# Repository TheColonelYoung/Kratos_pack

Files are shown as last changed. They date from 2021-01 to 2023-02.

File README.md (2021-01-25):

# Kratos pack
Battery case with electronics for charging and protection of battery cells. Composes of 2s li-ion 3,7V battery cells. Includes undervoltage, overvoltage and overcurrent protection. As well as reverse voltage protection. Is charged from USB type-C connector. Support statistics over USB and have battery voltage indication via RGB LED.

 Front | Back |
-------------------------|-------------------------|
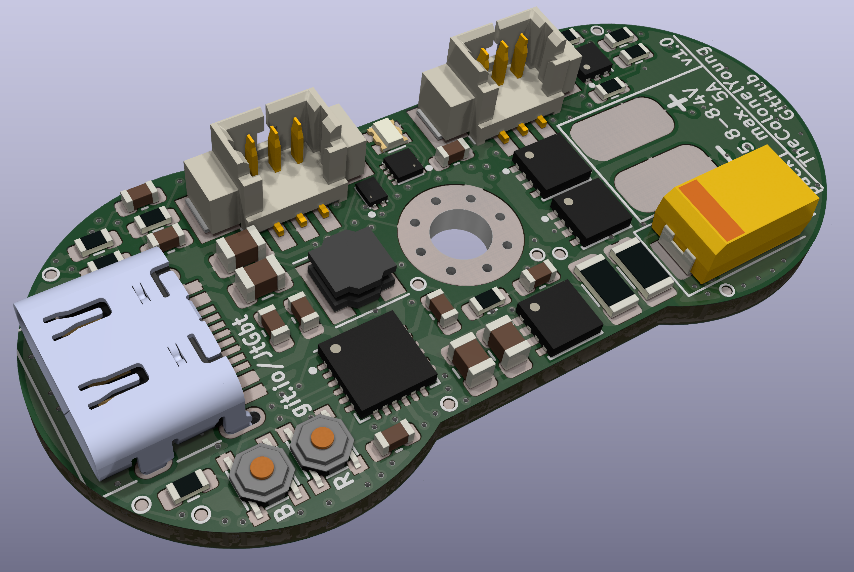
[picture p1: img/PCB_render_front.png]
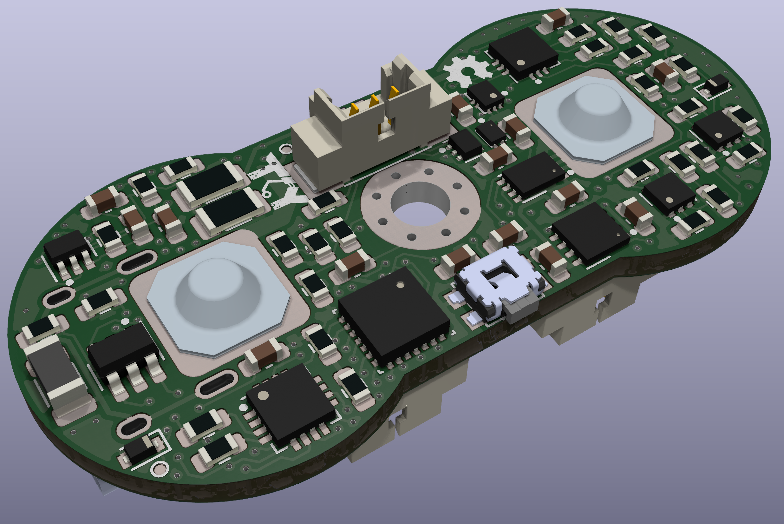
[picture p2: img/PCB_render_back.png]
 | 

PCB is placed on top of batteries, so contact on bottom of board touch positive side of one battery and negative of other.
On other side batteries are connected only with metal bridge with spring contact to which is soldered cable which leads to connector on board. This wire is used to read voltage of individual batteries and balance then during charging.

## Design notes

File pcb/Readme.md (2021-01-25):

# PCB parameter
- 4 layer PCB
- 1 oz copper
- Minimal trace width 0.127 mm
- Via drilling 0.2, via copper 0.45 mm
- Thickness 1.6 mm
- Dimensions: 44.2 x 20.2 mm

# Connectors
### USB-C
- Supports USB 2.0
- Current up to 3A
- Bottom plastic bump for alignment should be removed to fit to board

### PROG connector
- Used to program STM32 microcontroller
- Contains SWD interface

### Debug connector
- Used to debug code in microcontroller
- Contains UART2 od microcontroller
- Pins: ground, RX, TX

### Battery connector
- Connects between batteries and to termistor
- Connect in midpoint of battery pack, used to sense voltage and ballance cells

### Output leads
- Solder pads for output wire
- Preferred connector on output is male XT30
- Output wire should be fixed with some type of strain relief

# Links
- 3 pin connectors 
    - Male [Mouser](https://mouser.com/ProductDetail/649-10114826-00003/)
    - Female [Mouser](https://mouser.com/ProductDetail/649-10114828-11103LF/)
    - Terminals [Mouser](https://mouser.com/ProductDetail/649-10114827-002LF/)
- Horizontal tactile switch [Mouser](https://mouser.com/ProductDetail/667-EVQP7J01P/)
- Tactile switches [Mouser](https://mouser.com/ProductDetail/611-KMT031NGJLHS/)
- LED 0606 [Mouser](https://mouser.com/ProductDetail/710-150066M153000/)
- LED Driver [Mouser](https://mouser.com/ProductDetail/389-KTD2026BEWETR/)

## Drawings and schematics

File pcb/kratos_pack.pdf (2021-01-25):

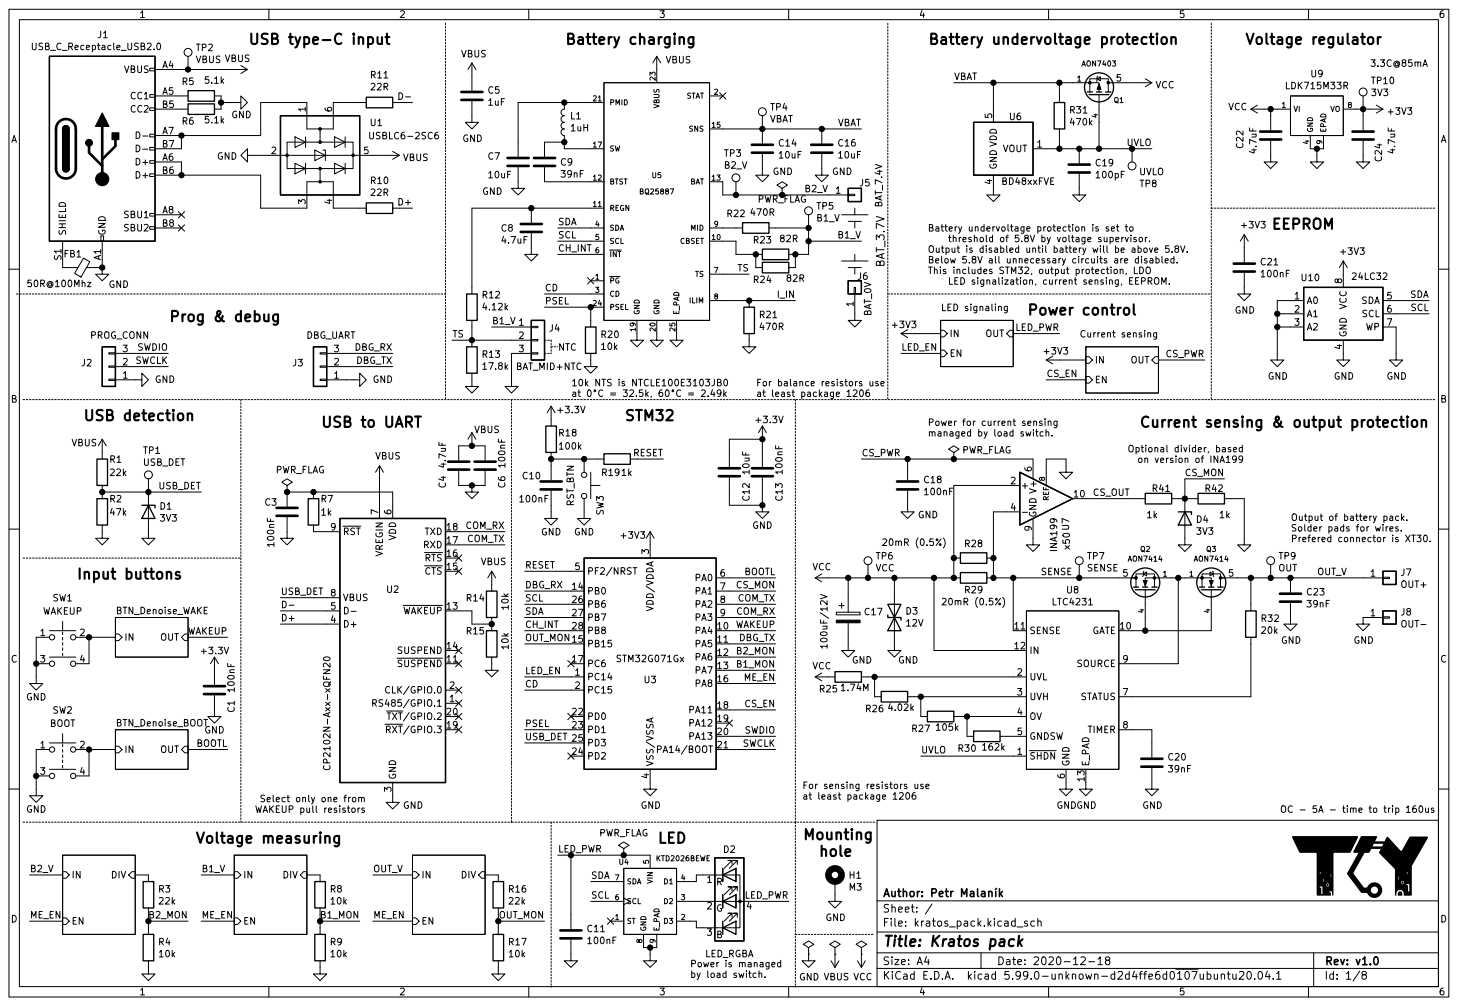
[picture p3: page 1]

on version of INA199 Voltage regulator

Solder pads for wires. Prefered connector is XT30. BAT_3.7V

Battery undervoltage protection is set to
threshold of 5.8V by voltage supervisor.
Output is disabled until battery will be above 5.8V.
Below 5.8V all unnecessary circuits are disabled.
This includes STM32, output protection, LDO

Power control For balance resistors use

4 SDA 5 SCL 6 WP 7 VCC

Power for current sensing

Output of battery pack.

6 STATUS 7 TIMER 8 SOURCE 9 GATE 10 SENSE 11

For sensing resistors use
at least package 1206

Select only one from
WAKEUP pull resistors

OC - 5A - time to trip 160us

Id: 1/8 Title: Kratos pack

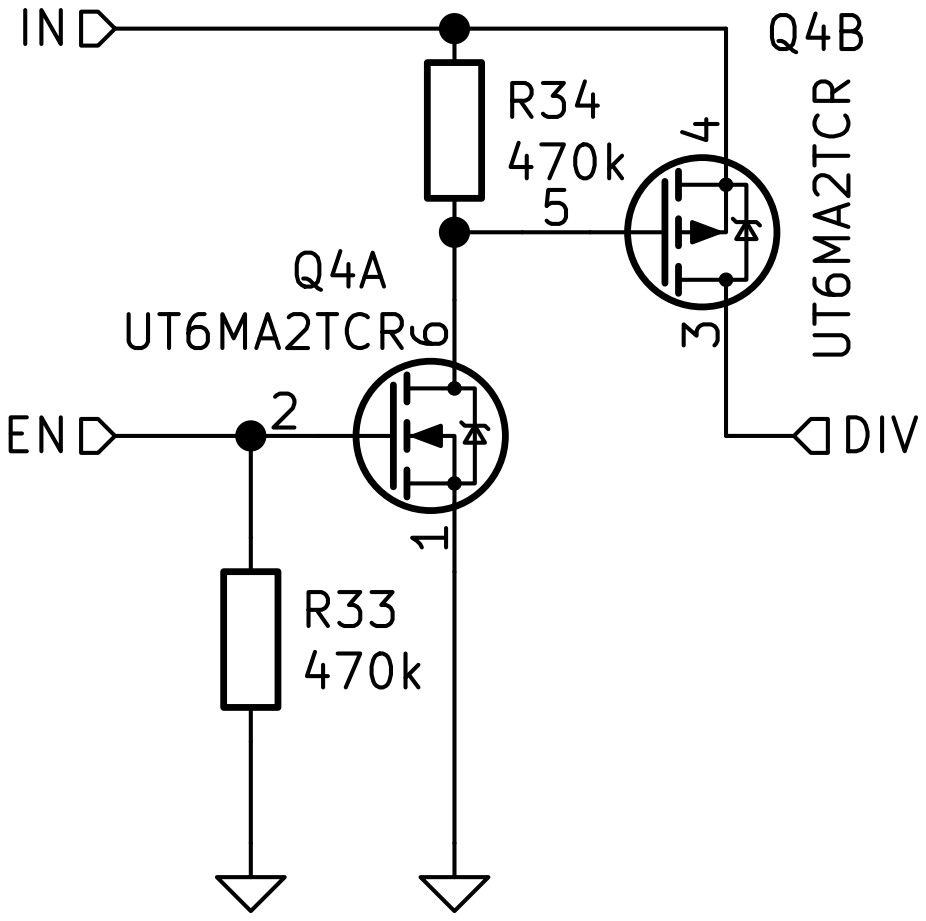
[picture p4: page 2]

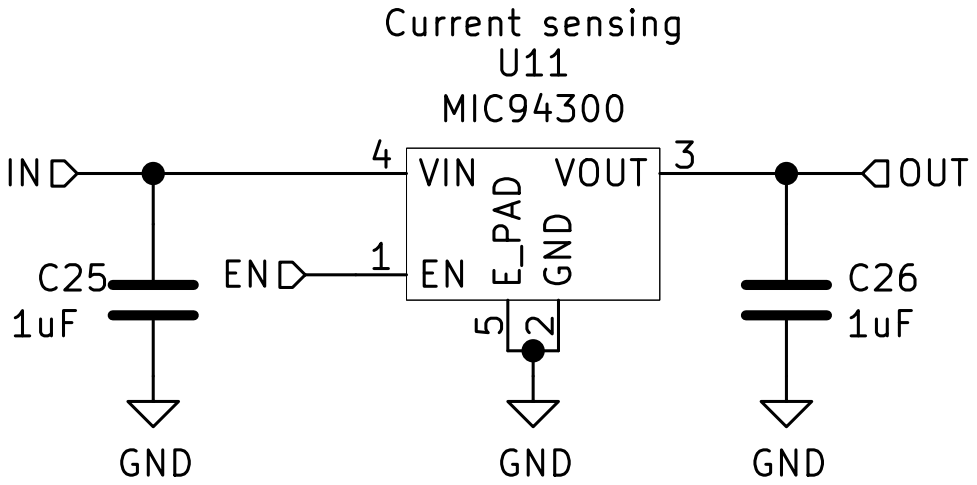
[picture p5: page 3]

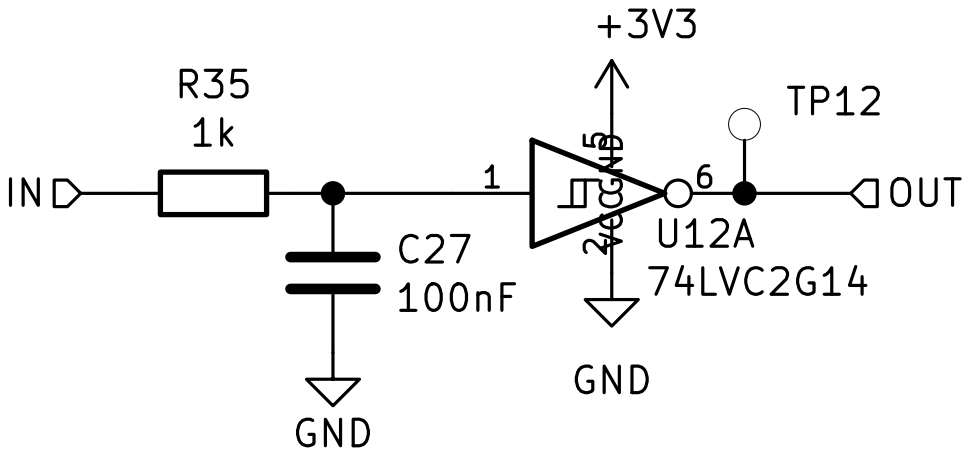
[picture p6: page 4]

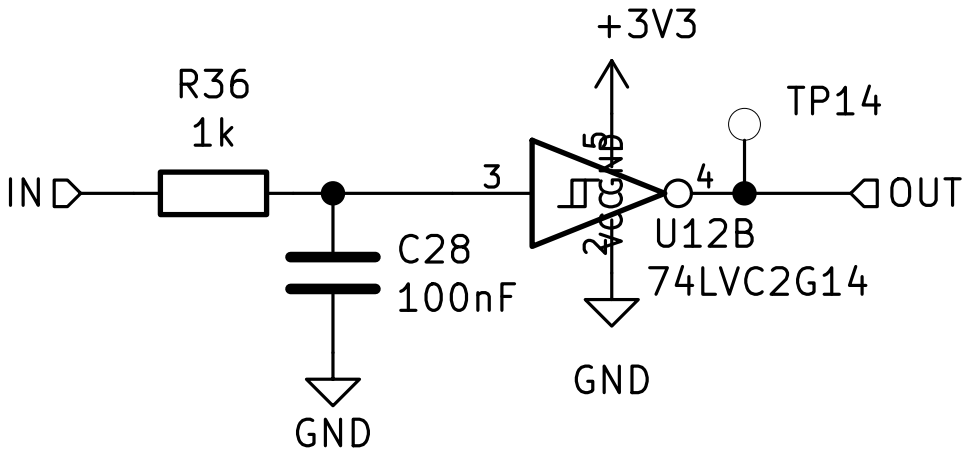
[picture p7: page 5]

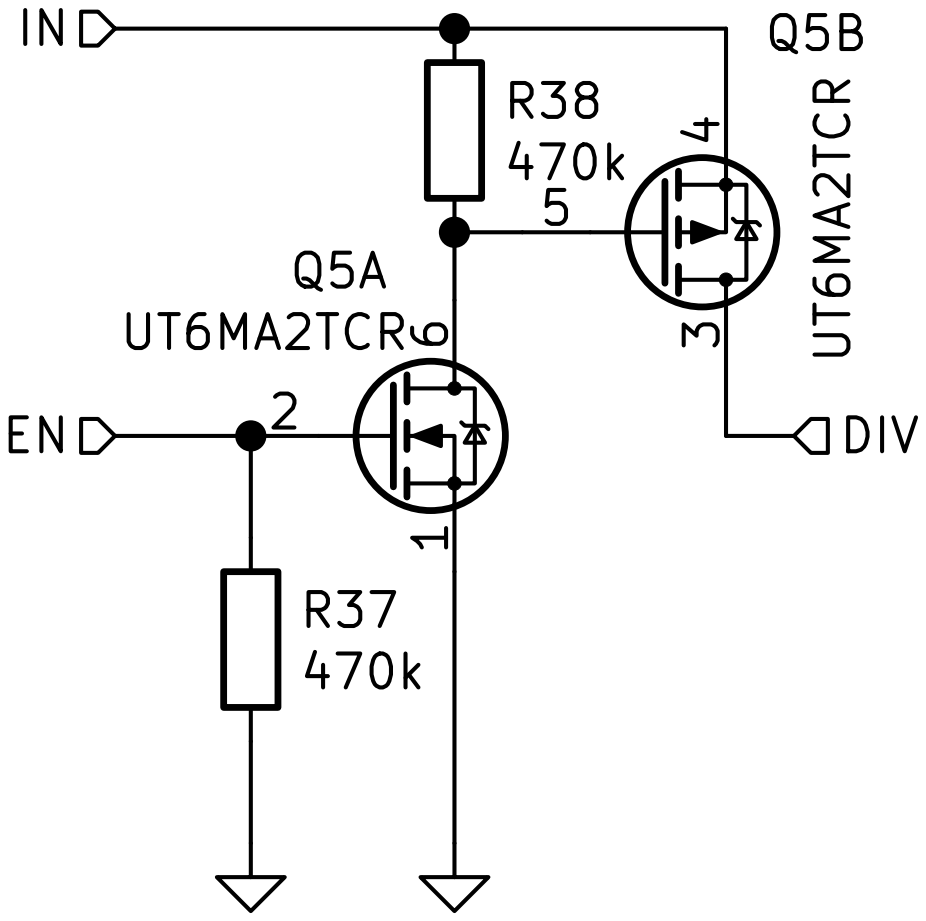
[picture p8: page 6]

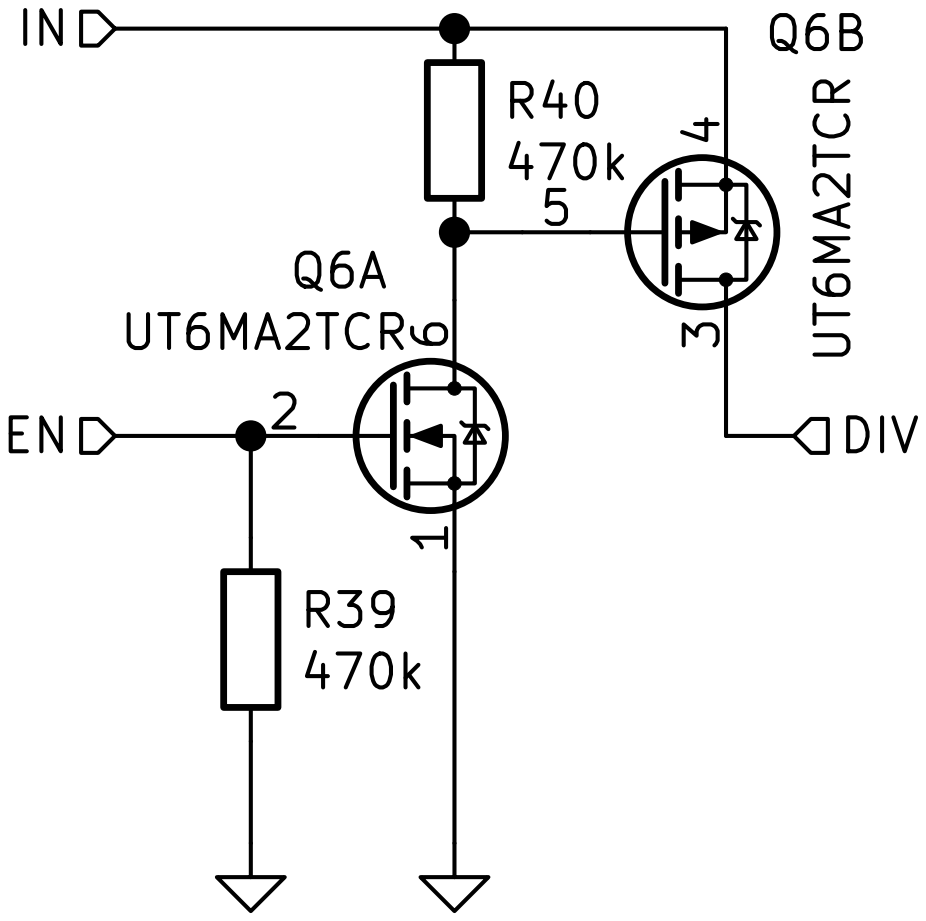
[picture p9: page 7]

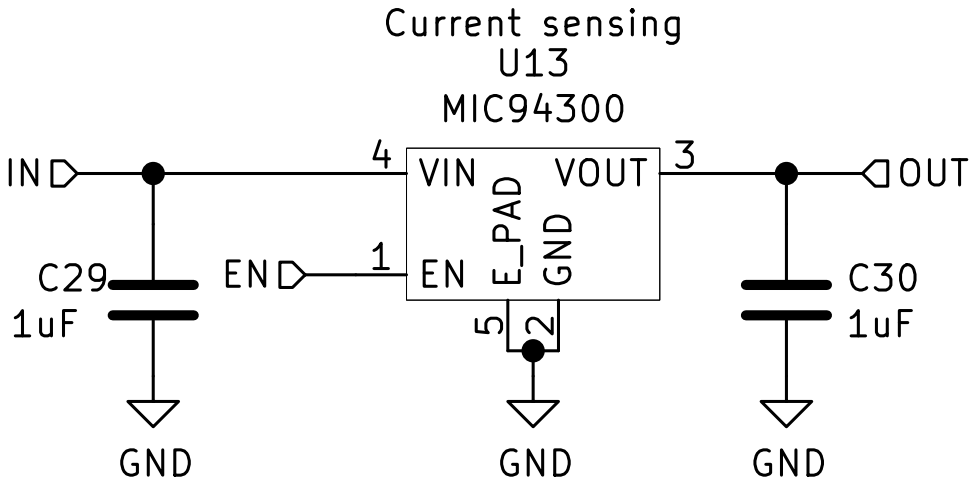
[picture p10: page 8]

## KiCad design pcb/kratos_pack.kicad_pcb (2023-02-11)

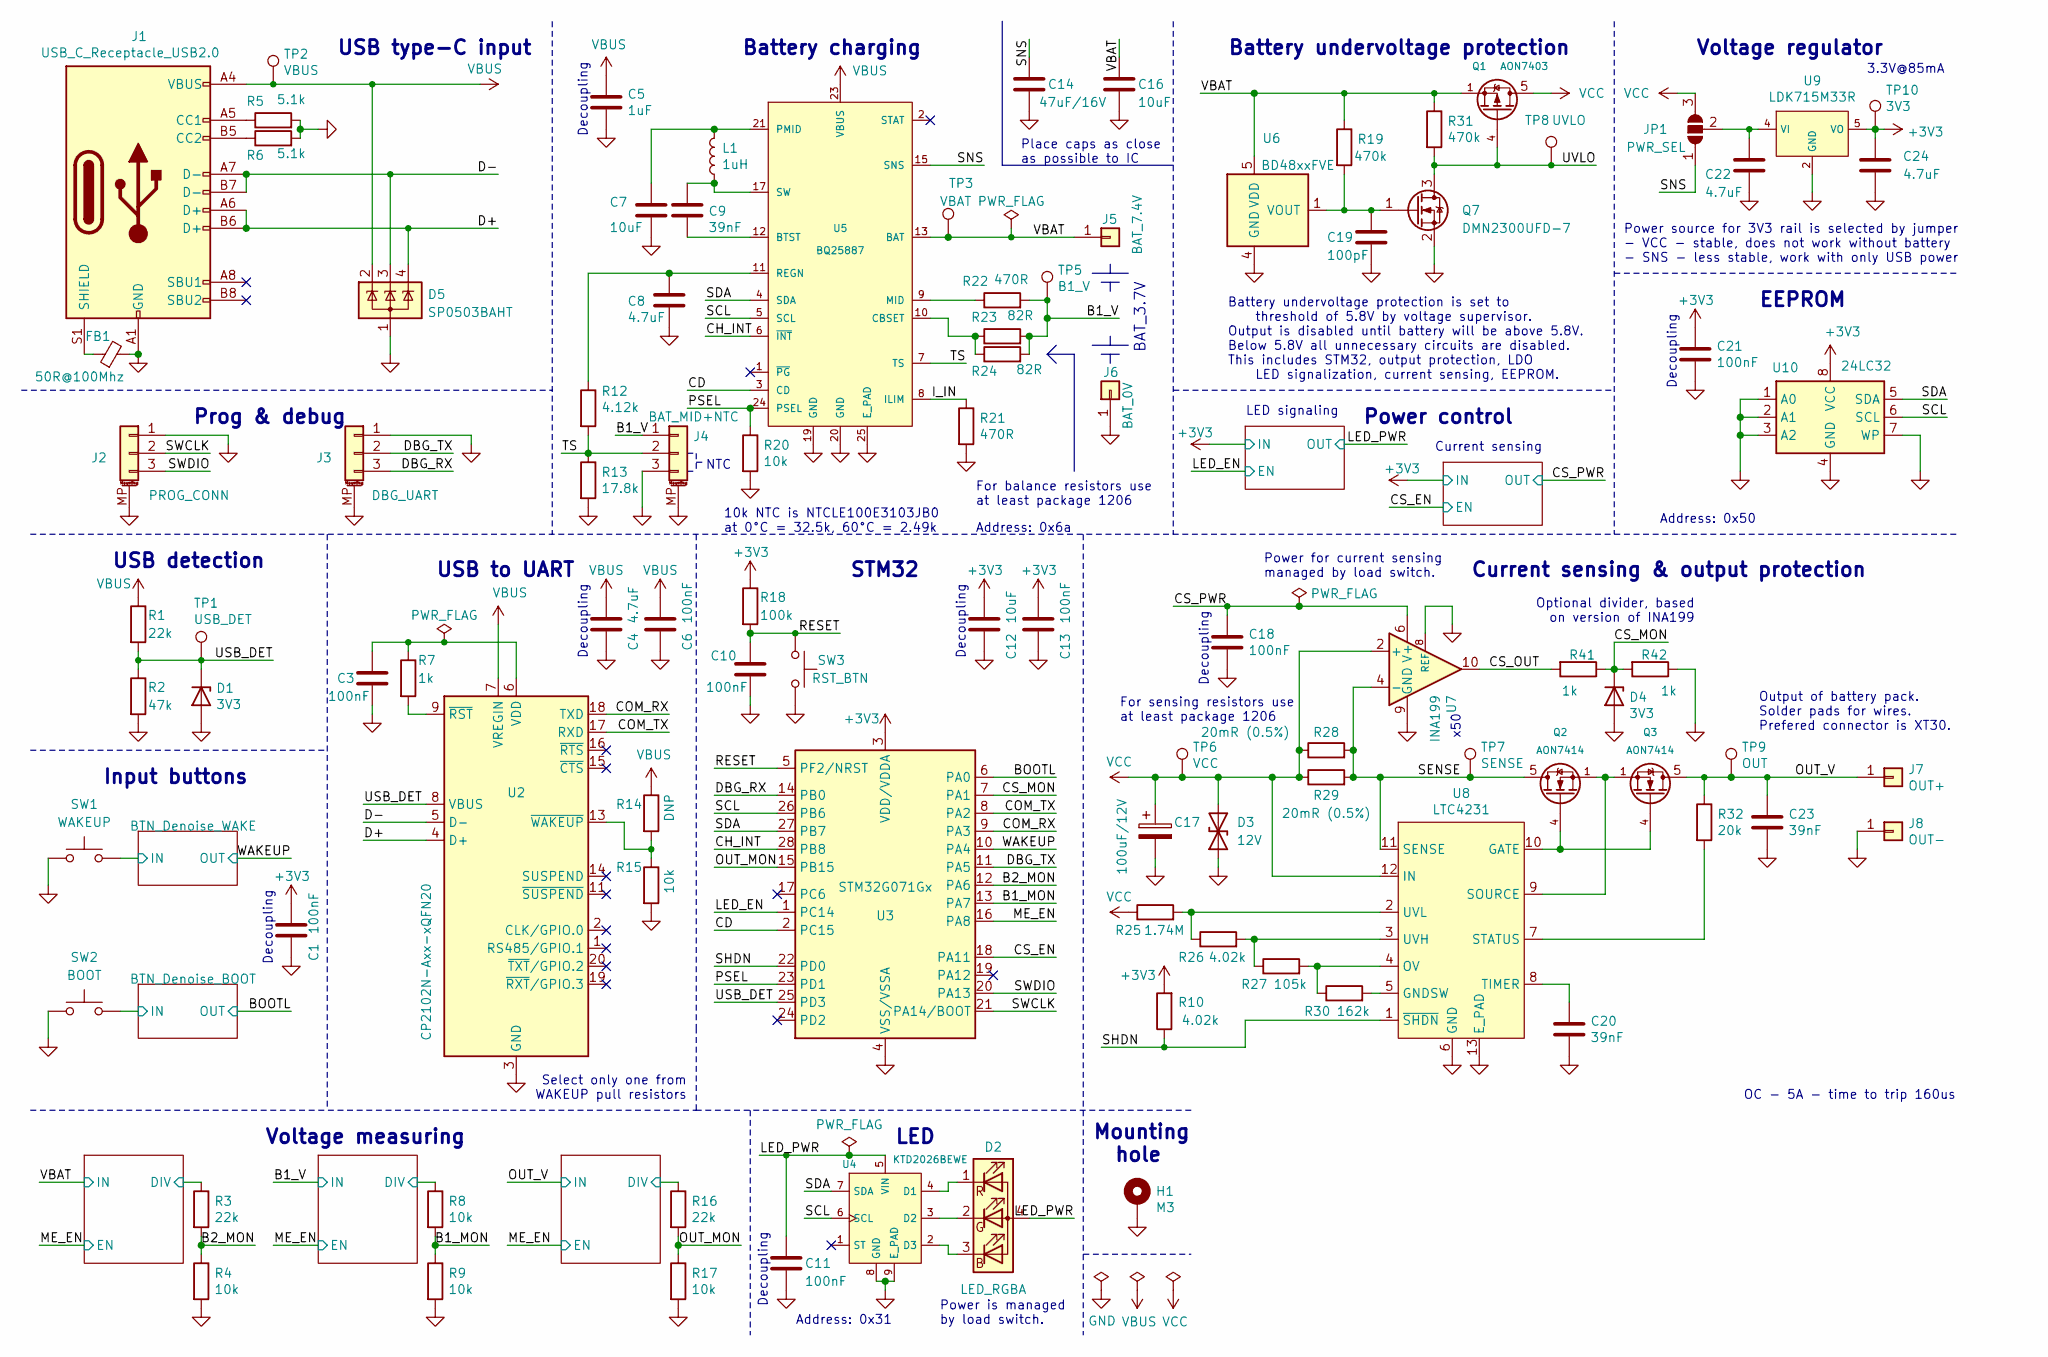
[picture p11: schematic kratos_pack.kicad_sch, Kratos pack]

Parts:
C1, C3, C6, C10, C11, C13, C18, C21: 100nF; C_0603_1608Metric
C4, C8, C22, C24: 4.7uF; C_0603_1608Metric
C5: 1uF; C_0603_1608Metric
C7, C12, C16: 10uF; C_0805_2012Metric
C9, C20, C23: 39nF; C_0603_1608Metric
C14: 47uF/16V; C_1206_3216Metric
C17: 100uF/12V; CP_EIA-7343-31_Kemet-D
C19: 100pF; C_0603_1608Metric
D1, D4: 3V3; D_SOD-523
D2: LED_RGBA; WL-SFCD - RGB606
D3: 12V; D_0603_1608Metric
D5: SP0503BAHT; SOT-143
FB1: 50R@100Mhz; L_1206_3216Metric
H1: M3; MountingHole_3.2mm_M3_Pad_Via
J1: USB_C_Receptacle_USB2.0; USB_C_Receptacle_HRO_TYPE-C-31-M-12
J2: PROG_CONN; Amphenol_10114828-11103LF_1x03_P1.25mm_Vertical
J3: DBG_UART; Amphenol_10114828-11103LF_1x03_P1.25mm_Vertical
J4: BAT_MID+NTC; Amphenol_10114828-11103LF_1x03_P1.25mm_Vertical
J5: BAT_7.4V; 18650_contact_bump
J6: BAT_0V; 18650_contact_bump
J7: OUT+; WirePad_SMD_1x_3x6mm
J8: OUT-; WirePad_SMD_1x_3x6mm
JP1: PWR_SEL; SolderJumper-3_P0.75mm_Open_Pad0.5x0.8mm
L1: 1uH; L_Taiyo-Yuden_MD-4040
Q1: AON7403; DFN-8-1EP_3x3mm_P0.65mm_EP1.55x2.4mm
Q2, Q3: AON7414; DFN-8-1EP_3x3mm_P0.65mm_EP1.55x2.4mm
Q7: DMN2300UFD-7; DFN-3_1.2x1.2mm
R1, R3, R16: 22k; R_0603_1608Metric
R2: 47k; R_0603_1608Metric
R4, R8, R9, R15, R17, R20: 10k; R_0603_1608Metric
R5, R6: 5.1k; R_0603_1608Metric
R7, R41, R42: 1k; R_0603_1608Metric
R10, R26: 4.02k; R_0603_1608Metric
R12: 4.12k; R_0603_1608Metric
R13: 17.8k; R_0603_1608Metric
R14: DNP; R_0603_1608Metric
R18: 100k; R_0603_1608Metric
R19, R31: 470k; R_0603_1608Metric
R21, R22: 470R; R_0603_1608Metric
R23, R24: 82R; R_1206_3216Metric
R25: 1.74M; R_0603_1608Metric
R27: 105k; R_0603_1608Metric
R28, R29: 20mR (0.5%); R_1206_3216Metric
R30: 162k; R_0603_1608Metric
R32: 20k; R_0603_1608Metric
SW1: WAKEUP; EVQ-P7J01P
SW2: BOOT; KMT031NGJLHS
SW3: RST_BTN; KMT031NGJLHS
TP1: USB_DET; TestPoint_Pad_D0.5mm
TP2: VBUS; TestPoint_Pad_D0.5mm
TP3: VBAT; TestPoint_Pad_D0.5mm
TP5: B1_V; TestPoint_Pad_D0.5mm
TP6: VCC; TestPoint_Pad_D0.5mm
TP7: SENSE; TestPoint_Pad_D0.5mm
TP8: UVLO; TestPoint_Pad_D0.5mm
TP9: OUT; TestPoint_Pad_D0.5mm
TP10: 3V3; TestPoint_Pad_D0.5mm
U2: CP2102N-Axx-xQFN20; SiliconLabs_QFN-20-1EP_3x3mm_P0.5mm_EP1.8x1.8mm
U3: STM32G071Gx; QFP-28_4x4_Pitch0.5mm
U4: KTD2026BEWE; UTDFN-8-1EP_1.5x1.5mm_P0.4mm_EP0.8x1.45mm
U5: BQ25887; QFN-24-1EP_4x4mm_P0.5mm_EP2.6x2.6mm
U6: BD48xxFVE; VSOF5
U7: INA199; UQFN-10_1.4x1.8mm_P0.4mm
U8: LTC4231; QFN-12-1EP_3x3mm_P0.5mm_EP1.65x1.65mm_ThermalVias
U9: LDK715M33R; SOT-23-5
U10: 24LC32; DFN-8-1EP_3x2mm_P0.5mm_EP1.3x1.5mm

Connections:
+3V3: C1.1, C12.1, C13.1, C21.1, C24.1, R10.2, R18.1, TP10.1, U3.3 (VDD/VDDA), U9.5 (VO), U10.8 (VCC); also elsewhere on the board
/B1_MON: R8.2, R9.1, U3.13 (PA7)
/B1_V: J4.1, R22.2, R23.2, R24.2, TP5.1; also elsewhere on the board
/B2_MON: R3.2, R4.1, U3.12 (PA6)
/BOOTL: U3.6 (PA0); also elsewhere on the board
/BTN_Denoise_BOOT/IN: SW2.2; also elsewhere on the board
/BTN_Denoise_WAKE/IN: SW1.2; also elsewhere on the board
/CD: U3.2 (PC15), U5.3 (CD)
/CH_INT: U3.28 (PB8), U5.6 (~INT)
/COM_RX: U2.18 (TXD), U3.9 (PA3)
/COM_TX: U2.17 (RXD), U3.8 (PA2)
/CS_EN: U3.18 (PA11); also elsewhere on the board
/CS_MON: D4.1 (K), R41.1, R42.2, U3.7 (PA1)
/CS_OUT: R41.2, U7.10
/CS_PWR: C18.1, U7.6 (V+); also elsewhere on the board
/D+: D5.4 (K), J1.A6 (D+), J1.B6 (D+), U2.4 (D+)
/D-: D5.3 (K), J1.A7 (D-), J1.B7 (D-), U2.5 (D-)
/DBG_RX: J3.3, U3.14 (PB0)
/DBG_TX: J3.2, U3.11 (PA5)
/I_IN: R21.1, U5.8 (ILIM)
/LED_EN: U3.1 (PC14); also elsewhere on the board
/LED_PWR: C11.1, D2.4 (A), U4.5 (VIN); also elsewhere on the board
/ME_EN: U3.16 (PA8); also elsewhere on the board
/OUT_MON: R16.2, R17.1, U3.15 (PB15)
/OUT_V: C23.1, J7.1, Q3.5 (D), Q3.6 (D), Q3.7 (D), Q3.8 (D), Q3.9 (D), R32.1, TP9.1; also elsewhere on the board
/PSEL: R20.1, U3.23 (PD1), U5.24 (PSEL)
/RESET: C10.1, R18.2, SW3.1, U3.5 (PF2/NRST)
/SCL: U3.26 (PB6), U4.6 (SCL), U5.5 (SCL), U10.6 (SCL)
/SDA: U3.27 (PB7), U4.7 (SDA), U5.4 (SDA), U10.5 (SDA)
/SENSE: Q2.5 (D), Q2.6 (D), Q2.7 (D), Q2.8 (D), Q2.9 (D), R28.2, R29.2, TP7.1, U7.4 (-), U7.5 (-), U8.11 (SENSE)
/SHDN: R10.1, U3.22 (PD0), U8.1 (~SHDN)
/SNS: C14.1, JP1.1 (A), U5.15 (SNS), U5.16 (SNS)
/SWCLK: J2.2, U3.21 (PA14/BOOT)
/SWDIO: J2.3, U3.20 (PA13)
/TS: J4.2, R12.2, R13.1, U5.7 (TS)
/USB_DET: D1.1 (K), R1.2, R2.1, TP1.1, U2.8 (VBUS), U3.25 (PD3)
/UVLO: Q1.4 (G), Q7.3 (D), R31.2, TP8.1
/VBAT: C16.1, J5.1, Q1.1 (S), Q1.2 (S), Q1.3 (S), R19.1, R31.1, TP3.1, U5.13 (BAT), U5.14 (BAT), U6.5 (VDD); also elsewhere on the board
/Voltage_measuring1/DIV: R8.1; also elsewhere on the board
/Voltage_measuring2/DIV: R16.1; also elsewhere on the board
/Voltage_measuring/DIV: R3.1; also elsewhere on the board
/WAKEUP: U3.10 (PA4); also elsewhere on the board
GND: C1.2, C3.2, C4.2, C5.2, C6.2, C7.2, C8.1, C10.2, C11.2, C12.2, C13.2, C14.2, C16.2, C17.2, C18.2, C19.2, C20.2, C21.2, C22.2, C23.2, C24.2, D1.2 (A), D3.1 (A1), D4.2 (A), D5.1 (A), FB1.2, H1.1, J1.A1 (GND), J1.A12 (GND), J1.B1 (GND), J1.B12 (GND), J2.1, J2.MP (MountPin), J3.1, J3.MP (MountPin), J4.3, J4.MP (MountPin), J6.1, J8.1, Q7.2 (S), R2.2, R4.2, R5.2, R6.2, R9.2, R13.2, R15.2, R17.2, R20.2, R21.2, R42.1, SW1.1, SW2.1, SW3.2, U2.3 (GND), U2.12 (GND), U2.21 (GND), U3.4 (VSS/VSSA), U4.8 (GND), U4.9 (E_PAD), U5.19 (GND), U5.20 (GND), U5.25 (E_PAD), U6.2 (GND), U6.4 (GND), U7.8 (REF), U7.9 (GND), U8.6 (GND), U8.13 (E_PAD), U9.2 (GND), U10.1 (A0), U10.2 (A1), U10.3 (A2), U10.4 (GND), U10.7 (WP); also elsewhere on the board
unnamed: C3.1, R7.1, U2.6 (VDD)
unnamed: C7.1, L1.2, U5.21 (PMID), U5.22 (PMID)
unnamed: C8.2, R12.1, U5.11 (REGN)
unnamed: C9.1, U5.12 (BTST)
unnamed: C9.2, L1.1, U5.17 (SW), U5.18 (SW)
unnamed: C19.1, Q7.1 (G), R19.2, U6.1 (VOUT)
unnamed: C20.1, U8.8 (TIMER)
unnamed: C22.1, JP1.2 (C), U9.4 (VI)
unnamed: D2.1 (RK), U4.4 (D1)
unnamed: D2.2 (GK), U4.3 (D2)
unnamed: D2.3 (BK), U4.2 (D3)
unnamed: FB1.1, J1.S1 (SHIELD)
unnamed: J1.A5 (CC1), R5.1
unnamed: J1.B5 (CC2), R6.1
unnamed: Q2.1 (S), Q2.2 (S), Q2.3 (S), Q3.1 (S), Q3.2 (S), Q3.3 (S), U8.9 (SOURCE)
unnamed: Q2.4 (G), Q3.4 (G), U8.10 (GATE)
unnamed: R7.2, U2.9 (~RST)
unnamed: R14.2, R15.1, U2.13 (~WAKEUP)
unnamed: R22.1, U5.9 (MID)
unnamed: R23.1, R24.1, U5.10 (CBSET)
unnamed: R25.2, R26.1, U8.2 (UVL)
unnamed: R26.2, R27.1, U8.3 (UVH)
unnamed: R27.2, R30.1, U8.4 (OV)
unnamed: R30.2, U8.5 (GNDSW)
unnamed: R32.2, U8.7 (STATUS)
VBUS: C4.1, C5.1, C6.1, D5.2 (K), J1.A4 (VBUS), J1.A9 (VBUS), J1.B4 (VBUS), J1.B9 (VBUS), R1.1, R14.1, TP2.1, U2.7 (VREGIN), U5.23 (VBUS)
VCC: C17.1, D3.2 (A2), JP1.3 (B), Q1.5 (D), Q1.6 (D), Q1.7 (D), Q1.8 (D), Q1.9 (D), R25.1, R28.1, R29.1, TP6.1, U7.2 (+), U7.3 (+), U8.12 (IN)

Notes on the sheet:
Decoupling
Address: 0x31
For sensing resistors use at least package 1206
Power control
OC - 5A - time to trip 160us
Current sensing
Address: 0x50
Power is managed by load switch.
LED
For balance resistors use at least package 1206
NTC
Output of battery pack. Solder pads for wires. Prefered connector is XT30.
USB type-C input
USB detection
Battery charging
Voltage regulator
Power source for 3V3 rail is selected by jumper - VCC - stable, does not work without battery - SNS - less stable, work with only USB power
x50
Prog & debug
LED signaling
Optional divider, based on version of INA199
Battery undervoltage protection is set to threshold of 5.8V by voltage supervisor. Output is disabled until battery will be above 5.8V. Below 5.8V all unnecessary circuits are disabled. This includes STM32, output protection, LDO LED signalization, current sensing, EEPROM.
BAT_3.7V
Select only one from WAKEUP pull resistors
3.3V@85mA
USB to UART
Address: 0x6a
10k NTC is NTCLE100E3103JB0 at 0°C = 32.5k, 60°C = 2.49k
Power for current sensing managed by load switch.
EEPROM
Current sensing & output protection
STM32
Place caps as close as possible to IC
Mounting hole
Input buttons
Voltage measuring
Battery undervoltage protection

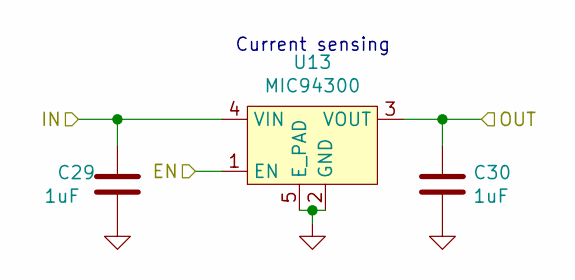
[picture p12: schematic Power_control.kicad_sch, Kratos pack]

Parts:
C29, C30: 1uF; C_0603_1608Metric
U13: MIC94300; MLF-4_1.2x1.6mm_P0.5_1EP_0.85x0.5mm

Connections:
+3V3: C29.1, U13.4 (VIN); also elsewhere on the board
/LED_EN: U13.1 (EN); also elsewhere on the board
/LED_PWR: C30.1, U13.3 (VOUT); also elsewhere on the board
GND: C29.2, C30.2, U13.2 (GND), U13.5 (E_PAD); also elsewhere on the board

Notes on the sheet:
Current sensing

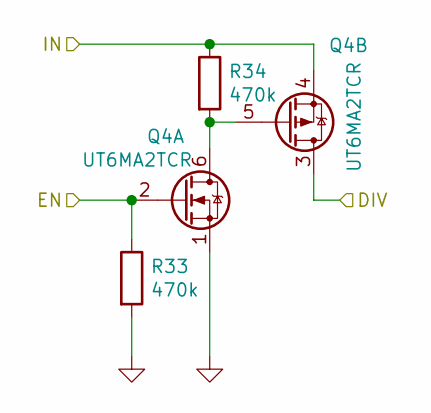
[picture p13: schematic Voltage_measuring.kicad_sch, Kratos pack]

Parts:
Q4: UT6MA2TCR; UDFN-6-2EP_2x2mm_P0.65mm_EP1x0.7mm
R33, R34: 470k; R_0603_1608Metric

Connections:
/ME_EN: Q4.2 (GN), R33.1; also elsewhere on the board
/VBAT: Q4.4 (SP), Q4.8 (SP), R34.1; also elsewhere on the board
/Voltage_measuring/DIV: Q4.3 (DP); also elsewhere on the board
GND: Q4.1 (SN), R33.2; also elsewhere on the board
unnamed: Q4.5 (GP), Q4.6 (DN), Q4.7 (DN), R34.2

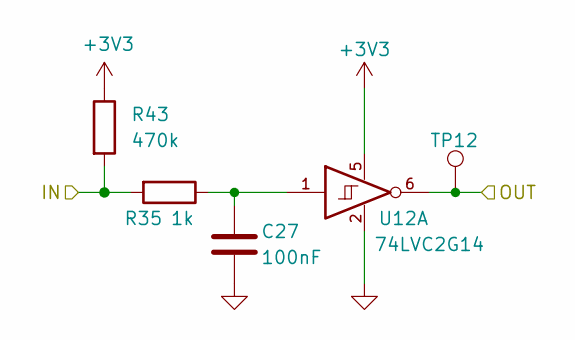
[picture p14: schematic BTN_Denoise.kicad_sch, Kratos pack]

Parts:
C27: 100nF; C_0603_1608Metric
R35: 1k; R_0603_1608Metric
R43: 470k; R_0603_1608Metric
TP12: TestPoint; TestPoint_Pad_D0.5mm
U12: 74LVC2G14; SOT-363_SC-70-6

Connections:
+3V3: R43.1, U12.5; also elsewhere on the board
/BOOTL: U12.4; also elsewhere on the board
/BTN_Denoise_WAKE/IN: R35.2, R43.2; also elsewhere on the board
/WAKEUP: TP12.1, U12.6; also elsewhere on the board
GND: C27.2, U12.2; also elsewhere on the board
unnamed: C27.1, R35.1, U12.1
unnamed 52: U12.3; also elsewhere on the board

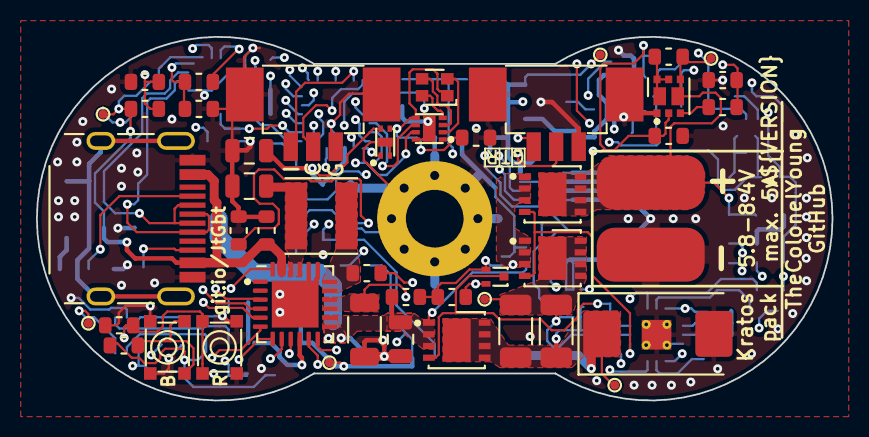
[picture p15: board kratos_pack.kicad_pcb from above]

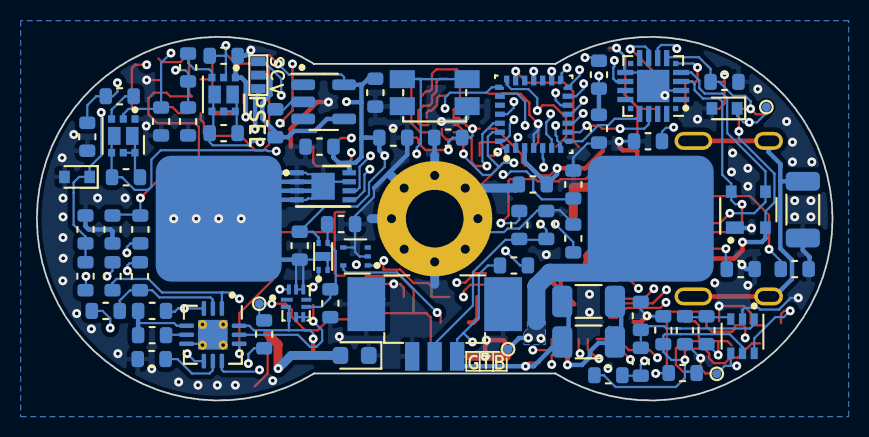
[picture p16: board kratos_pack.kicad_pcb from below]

Board: 4 copper layers, 44.2 x 20.2 mm, 121 parts (73 on the bottom side), 75 nets.

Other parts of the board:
C25, C26: 1uF; C_0603_1608Metric
C28: 100nF; C_0603_1608Metric
Q5, Q6: UT6MA2TCR; UDFN-6-2EP_2x2mm_P0.65mm_EP1x0.7mm
R36: 1k; R_0603_1608Metric
R37, R38, R39, R40, R44: 470k; R_0603_1608Metric
TP14: TestPoint; TestPoint_Pad_D0.5mm
U11: MIC94300; MLF-4_1.2x1.6mm_P0.5_1EP_0.85x0.5mm

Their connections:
+3V3: C25.1, R44.1, U11.4 (VIN); also elsewhere on the board
/B1_V: Q5.4 (SP), Q5.8 (SP), R38.1; also elsewhere on the board
/BOOTL: TP14.1; also elsewhere on the board
/BTN_Denoise_BOOT/IN: R36.2, R44.2; also elsewhere on the board
/CS_EN: U11.1 (EN); also elsewhere on the board
/CS_PWR: C26.1, U11.3 (VOUT); also elsewhere on the board
/ME_EN: Q5.2 (GN), Q6.2 (GN), R37.1, R39.1; also elsewhere on the board
/OUT_V: Q6.4 (SP), Q6.8 (SP), R40.1; also elsewhere on the board
/Voltage_measuring1/DIV: Q5.3 (DP); also elsewhere on the board
/Voltage_measuring2/DIV: Q6.3 (DP); also elsewhere on the board
GND: C25.2, C26.2, C28.2, Q5.1 (SN), Q6.1 (SN), R37.2, R39.2, U11.2 (GND), U11.5 (E_PAD); also elsewhere on the board
unnamed 52: C28.1, R36.1; also elsewhere on the board
unnamed: Q5.5 (GP), Q5.6 (DN), Q5.7 (DN), R38.2
unnamed: Q6.5 (GP), Q6.6 (DN), Q6.7 (DN), R40.2

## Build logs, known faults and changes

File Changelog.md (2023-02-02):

# 1.2
- Disconnect ~SHDN of LTC4231 from voltage supervisor UVLO signal
- Enable MCU to control shutdown (~SHDN input) of LTC4231 by pin 22 of MCU (PD0)
- Fix MOSFET type which inverts voltage supervisor logic level
- Selectable power input for 3V3 rail (SNS of battery charger or VCC) ???
    - SNS is but unstable and noisy but work with USB connected and battery disconnected
    - VCC is stable but unavailable when battery is disconnected (debug friendly)
    - Selectable by jumper next to regulator
- Fix USB detection by changing ESD protection and reconnecting USB detection

# 1.1
- Battery output is moved from SNS to VBAT pin of charger according to problem described in Errata sheet
    - This should make device more reliable during longer current consumption higher then 2A
    - Capacitor connected to SNS pins is changed for 47uF/16V in 1206 package
- Footprint of resistors and capacitors was exchanged for smaller versions
- Remove resistor in series with RESET line which is not required in order to save some space
- Fix under-voltage protection by inverting signal of under-voltage supervisor with MOSFET
- Fix MCU detection of USB connection, CP2102 is directly connected to VBUS
- Intended connection from ILIM pin to MCU is removed to avoid confusion
- Fix layout of signalization

# 1.0
- Initial release

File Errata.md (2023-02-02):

# V1.1  
- Incorrect MOSFET type Q7 
    - MOSFET is used for voltage supervisor inverting

- Incorrect logic level on LTC4231 
    - Inverted due to inversion of UVLO signal from voltage supervisor by Q7

- Problematic USB connection to CP2102 (USB<->UART converter)
    - Solved by removing ESD protection and 22R resistor on data lines
    - To connect pads 0R resistors could be used

# V1.0  

## Schema  
- Unconnected I_IN  
    - Output of battery charger on which could be measured voltage proportional to input current is unconnected due to space constraints  
    - This connection redundant, because current could be read from registers of battery charger IC  
    - Intended connection is removed in v1.1  

- SNS is used as output instead of BAT  
    - This was designed due to built in resistor inside battery charger IC, because then could be calculated consumption of inner components of device as MCU, USB to UART converter  
    - But power limitation of this sense resistor could lead to IC damage when current of 2A is long-term exceeded  
    - Fixed in v1.1  

## PCB  
- Voltage supervisor is not working  
    - Supervisor is active low but enable MOSFET is active high  
    - Partially solved by removing of supervisor  
    - Fixed in v1.1  

- Enable MOSFET for supervisor is not working  
    - Is pulled high by supervisor or by pull-up resistor  
    - Solution: Remove resistor R31  
    - Must by supplemented by pulldown resistor (otherwise gate of MOSFET will float)  
    - New resistor can be placed instead of C19  
    - Fixed in v1.1  

- Communication with MCU is not working  
    - Place only one resistor for CP2102 WAKEUP pin (preferably place only R15)  
    - Exchange R2 resistor value (47k -> 39k)  
    - Fixed in v1.1  

- Signaling LED has incorrect layout  
    - Solution: Is possible to solder LED turned by 90° clockwise  
    - Fixed in v1.1

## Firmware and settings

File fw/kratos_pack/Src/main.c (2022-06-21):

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
/* Includes ------------------------------------------------------------------*/
#include "main.h"

/* USER CODE BEGIN Includes */
#include "stm32g0xx_hal.h"

#include "device/device.hpp"
#include "led/KTD2026.hpp"
#include "apps/i2c_scanner.hpp"
/* USER CODE END Includes */

ADC_HandleTypeDef hadc1;

I2C_HandleTypeDef hi2c1;

TIM_HandleTypeDef htim2;

UART_HandleTypeDef huart2;
UART_HandleTypeDef huart3;

void SystemClock_Config(void);
static void MX_GPIO_Init(void);
static void MX_I2C1_Init(void);
static void MX_USART2_UART_Init(void);
static void MX_USART3_UART_Init(void);
static void MX_ADC1_Init(void);
static void MX_TIM2_Init(void);
/**
  * @brief  The application entry point.
  * @retval int
  */
int main(void){
    /* MCU Configuration--------------------------------------------------------*/

    /* Reset of all peripherals, Initializes the Flash interface and the Systick. */
    HAL_Init();

    /* Configure the system clock */
    SystemClock_Config();

    /* Initialize all configured peripherals */
    MX_GPIO_Init();
    MX_I2C1_Init();
    MX_USART2_UART_Init();
    MX_USART3_UART_Init();
    MX_ADC1_Init();
    MX_TIM2_Init();
    /* USER CODE BEGIN 2 */
    HAL_Delay(1);



    device()->mcu->UART_2->Send("Hello world\r\n");

    device()->Enable_CLI(device()->mcu->UART_2);
    device()->Enable_Filesystem();
    device()->cli->Enable_filesystem_executable(device()->fs);

    auto app = new I2C_scanner(device()->mcu->I2C_1);

    auto led_enable = new Pin('C', 14);
    led_enable->Set(true);

    auto led = new KTD2026(*(device()->mcu->I2C_1), 0b01100010);
    led->Test();

    /* USER CODE END 2 */

    /* Infinite loop */
    /* USER CODE BEGIN WHILE */
    while (1) {
        /* USER CODE END WHILE */

        /* USER CODE BEGIN 3 */
    }
    /* USER CODE END 3 */
} // main

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


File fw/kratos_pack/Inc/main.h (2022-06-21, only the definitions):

#define LED_EN_Pin GPIO_PIN_14
#define LED_EN_GPIO_Port GPIOC
#define CD_Pin GPIO_PIN_15
#define CD_GPIO_Port GPIOC
#define BOOT_Pin GPIO_PIN_0
#define BOOT_GPIO_Port GPIOA
#define CS_MON_Pin GPIO_PIN_1
#define CS_MON_GPIO_Port GPIOA
#define WAKEUP_Pin GPIO_PIN_4
#define WAKEUP_GPIO_Port GPIOA
#define B2_MON_Pin GPIO_PIN_6
#define B2_MON_GPIO_Port GPIOA
#define B1_MON_Pin GPIO_PIN_7
#define B1_MON_GPIO_Port GPIOA
#define OUT_MON_Pin GPIO_PIN_1
#define OUT_MON_GPIO_Port GPIOB
#define ME_EN_Pin GPIO_PIN_8
#define ME_EN_GPIO_Port GPIOA
#define CS_EN_Pin GPIO_PIN_11
#define CS_EN_GPIO_Port GPIOA
#define PSEL_Pin GPIO_PIN_3
#define PSEL_GPIO_Port GPIOB
#define USD_DET_Pin GPIO_PIN_5
#define USD_DET_GPIO_Port GPIOB
#define CH_INT_Pin GPIO_PIN_8
#define CH_INT_GPIO_Port GPIOB

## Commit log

2020-12-24 Schema: complete schematics of device
    [BTN_Denoise.kicad_sch, Power_control.kicad_sch, Voltage_measuring.kicad_sch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]
2021-01-12 Schema: bom optimization
    [Power_control.kicad_sch, Voltage_measuring.kicad_sch, kratos_pack.kicad_sch]
2021-01-12 Schema: update footprint 3-pin connectors, project cleanup, add gitignore
    [BTN_Denoise.kicad_sch, Power_control.kicad_sch, Voltage_measuring.kicad_sch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]
2021-01-14 Schema: Remove unnecessary test points (switches) and filtering capacitors (STM, CP2102)
    [BTN_Denoise.kicad_sch, Voltage_measuring.kicad_sch, kratos_pack.kicad_sch]
2021-01-14 PCB: Route USB input, charger circuit and switches
    [kratos_pack.kicad_pcb]
2021-01-14 Schema: add some connection STM32, remove redundant connections to BQ25887
    [BTN_Denoise.kicad_sch, Voltage_measuring.kicad_sch, kratos_pack.kicad_sch]
2021-01-14 PCB: routing of mcu, voltage mesuring, part of current sensing and power regulator
    [kratos_pack.kicad_pcb]
2021-01-15 FW: add connections for voltage measuring to MCU
2021-01-15 Schema: add connections from MCU to voltage measuring circuits
    [Power_control.kicad_sch, Voltage_measuring.kicad_sch, kratos_pack.kicad_sch]
2021-01-15 PCB: route power and voltage measuring
    [kratos_pack.kicad_pcb]
2021-01-15 FW: update connection of CS_EN pin
2021-01-15 Schema: update connection of CS_EN pin
    [BTN_Denoise.kicad_sch, Power_control.kicad_sch, Voltage_measuring.kicad_sch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]
2021-01-15 PCB: finalization of routing, add silk screen
    [kratos_pack.kicad_pcb]
2021-01-17 PCB: fix clearance based on JLCPCB capabilities
    [kratos_pack.kicad_pcb]
2021-01-17 BOM: update iBOM to new version of PCB
2021-01-25 FW: update pin mapping of MCU
2021-01-25 PCB: add 3D packages to parts
    [BTN_Denoise.kicad_sch, kratos_pack.kicad_pcb, kratos_pack.kicad_sch]
2021-01-25 PCB: update silk screen
    [kratos_pack.kicad_pcb]
2021-01-25 Schema: update page layout
    [kratos_pack.kicad_sch]
2021-01-25 Add renders of board, updates readme, add pdf with schematics
2021-02-01 Schema & PCB: add pull up to wakeup button
    [BTN_Denoise.kicad_sch, kratos_pack.kicad_pcb, kratos_pack.kicad_sch]
2021-02-01 PCB: connector mounting point to ground, change LDk package to SOT-23-5
    [BTN_Denoise.kicad_sch, kratos_pack.kicad_pcb, kratos_pack.kicad_sch]
2022-06-21 FW: add application for I2C scanning and communication testing
2022-06-21 Schema: update page layout and add I2C addresses to I2C device
    [BTN_Denoise.kicad_sch, Power_control.kicad_sch, Voltage_measuring.kicad_sch]
2022-06-21 PCB: update page layout and update to new version
    [kratos_pack.kicad_sch]
2022-07-25 Errata: add note about signaling LED footprint
2022-07-25 Schema & PCB: reconect output of charger from SNS to VBAT
    [BTN_Denoise.kicad_sch, Power_control.kicad_sch, Voltage_measuring.kicad_sch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]
2022-07-25 PCB: change footprint of resistors and capacitors to smaller version
    After first version is apparent that smaller footprint used on some
    resistors are big enough for manual soldering. Because of this was
    exchanged for custom smaller version.
    In current version pull-up resistor of reset circuit is not connected,
    because is mend to be removed in future.
    [BTN_Denoise.kicad_sch, Power_control.kicad_sch, Voltage_measuring.kicad_sch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]
2022-07-26 Schema & PCB: Remove resistor in series with RESET line
    Also some passive components around was shifter which resulted in better
    clearance from edge of PCB.
    [BTN_Denoise.kicad_sch, Power_control.kicad_sch, Voltage_measuring.kicad_sch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]
2022-07-26 Schema & PCB: exchange SNS capacitor of charger IC for 47uF/16V in 1206
    [BTN_Denoise.kicad_sch, Power_control.kicad_sch, Voltage_measuring.kicad_sch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]
2022-07-27 Schema & PCB: fix under-voltage supervisor by inverting output signal
    [kratos_pack.kicad_pcb, kratos_pack.kicad_sch]
2022-07-27 PCB: Fixed silkscreen overlapping issues (side button and USB connector)
    [kratos_pack.kicad_pcb]
2022-08-01 Schema & PCB: Fix USB detection by MCU and USB converter, hide GND labels
    USB detection circuit is now connected only to MCU.
    Converter from USB to UART (CP2102) is directly connected to VBUS.
    [BTN_Denoise.kicad_sch, Power_control.kicad_sch, Voltage_measuring.kicad_sch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]
2022-08-28 Schema: Removed intended ILIM connection, mirror connectors, fix typos
    [BTN_Denoise.kicad_sch, Power_control.kicad_sch, Voltage_measuring.kicad_sch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]
2022-08-28 PCB: Fix footprint of signalization LED
    [kratos_pack.kicad_pcb, kratos_pack.kicad_sch]
2023-02-02 Schema: fix USB connection
    [kratos_pack.kicad_sch]
2023-02-02 Schema & PCB: connect LTC4231 Shutdown pin to MCU GPIO
    [BTN_Denoise.kicad_sch, Power_control.kicad_sch, Voltage_measuring.kicad_sch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]
2023-02-02 PCB: fix USB connection, change ESD protection IC
    [kratos_pack.kicad_pcb]
2023-02-02 Schema: fix incorrect MOSFET model in UVLO invertor
    [kratos_pack.kicad_sch]
2023-02-02 Schema & PCB: add jumper selector for 3V3 rail regulator supply (VCC/SNS)
    [kratos_pack.kicad_pcb, kratos_pack.kicad_sch]
2023-02-11 PCB: layout optimization (around LTC4231 and center mounting hole to GND)
    [kratos_pack.kicad_pcb]
2023-02-12 Schema: shorten UVLo connection to avoid confusion (compared to prev. ver.)
    [kratos_pack.kicad_sch]

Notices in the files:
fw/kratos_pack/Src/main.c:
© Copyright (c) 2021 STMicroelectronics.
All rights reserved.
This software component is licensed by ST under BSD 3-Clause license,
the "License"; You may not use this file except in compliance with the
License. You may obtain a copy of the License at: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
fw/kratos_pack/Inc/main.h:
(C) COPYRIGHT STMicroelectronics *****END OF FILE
